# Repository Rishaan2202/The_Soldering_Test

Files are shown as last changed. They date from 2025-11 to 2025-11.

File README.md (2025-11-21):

# The_Soldering_Test
<h3> So this is a basic pcb, which has many kinda footprints in which we need to solder components, it has many basic and common footprints of SMT and THT devices, so that we could increase our soldering skills!!! </h3>
<br>
<br>

<h2> So here's the Schematic: </h2>
<br>

<br>
<br>

<h2> The PCB looks like this: </h2>
<br>

<br>
<h3> Front view </h3>
<br>

<h3> Back view </h3>
<br>

<br>
<br>

<h2> Here are the cart Pictures </h2>
<br>
<h3> The Parts' Cart: </h3>
<br>

<br>
<h3> The PCBs' Cart: </h3>

<br>
<br>

<h2> TYSM!!! </h2>

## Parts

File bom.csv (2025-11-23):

Designator | Footprint | Quantity | Value | LCSC Part # | Robocraze | Value (in USD)
C1, C2 | 402 | 2 | 10pF | C32949
C12, C13, C14, C16, C25 | 402 | 5 | 0.1uF | C1525
C15, C27, C28, C29 | 402 | 4 | 22uF | C105226
C17, C18, C19, C8 | 402 | 4 | 1uF | C52923
C23 | 402 | 1 | 4.7uF | C23733
C24, C26, C30, C31, C32, C6 | 402 | 6 | 10uF | C15525
D1, D2, D3 | 402 | 3 | LED | C30584803
IC1 | HSFPAR004A | 1 | HSFPAR004A | C470800
J1 | PinHeader_1x02_P2.54mm_Vertical_JST | 1 | Battery Connectors |  | 2.54mm pitch 2 pin JST Cable with Connector | 0.73
J2, J3 | PinHeader_1x04_P2.54mm_Vertical_Female | 1 | Conn_01x04 |  | 40x1 Female Berg Strip | 0.1
J6 | KH-TYPE-C-16P | 1 | USB Type-C Input | C709357
L1 | 805 | 1 | 1.5uH | C216155
Q1 | SOT-23 | 1 | SS8550 | C727138
R1 | 402 | 1 | 220Ω | C25091
R10, R12 | 402 | 2 | 1kΩ | C11702
R11 | 402 | 1 | 2kΩ | C4109
R14, R21 | 402 | 2 | 100kΩ | C25741
R15 | 402 | 1 | 470kΩ | C427225
R16 | 402 | 1 | 150kΩ | C2909320
R17, R24, R25, R30, R31, R32, R33, R34, R35, R36, R37 | 402 | 11 | 10kΩ | C25744
R2, R3 | 402 | 2 | 5kΩ | C5948099
R20 | 402 | 1 | 100Ω | C25076
R26, R27 | 402 | 2 | 22Ω | C25092
R28, R29 | 402 | 2 | 5.1kΩ | C25905
R5, R6, R8, R9 | 402 | 4 | 4.7kΩ | C25900
S1, S2 | SW_SKRPACE010 | 2 | SKRPACE010 | C139797
S3, S4 | Push Button | 2 | TS-1088-AR02016 | C720477
SW1 | SW_PCM12SMTR | 1 | PCM12SMTR | C221841
U1 | SOT-23-3L_AOS | 1 | AO3401A | C15127
U10 | VREG_TPS63070RNMR | 1 | TPS63070RNMR | C109322
U3 | WSON-8-1EP_2x2mm_P0.5mm_EP0.9x1.6mm_ThermalVias | 1 | TMP1075DSG | C2870250
U4 | ESP32-S3FN8 | 1 | ESP32-S3FN8 | C2913196
U5 | Crystal_SMD_3225-4Pin_3.2x2.5mm | 1 | SMD3225 | C5444549
U6 | SOP-16_3.9x9.9mm_P1.27mm | 1 | HX711 | C6705483
U9 | SOT23-6 | 1 | TP4057 | C725791
J7 | PinHeader_1x04_P2.54mm_Vertical_Male | 1 |  |  | 40x1 Pin 2.54mm Pitch Male Berg Strip | 0.056
Display1 | OLED Display | 1 |  |  | 0.96 Inch OLED Display Module SPI/I2C 4pin Blue Color | 3.52
GPS1 | GPS | 1 |  |  | Ublox Neo-6M GPS Module With EEPROM | 2.195
B1 | Li-ion Battery | 1 | Battery |  | Witty Fox 3.7V 2000 mAh Li-ion GPS Cylindrical Battery | 3.41
 |  |  |  |  |  | 10.011

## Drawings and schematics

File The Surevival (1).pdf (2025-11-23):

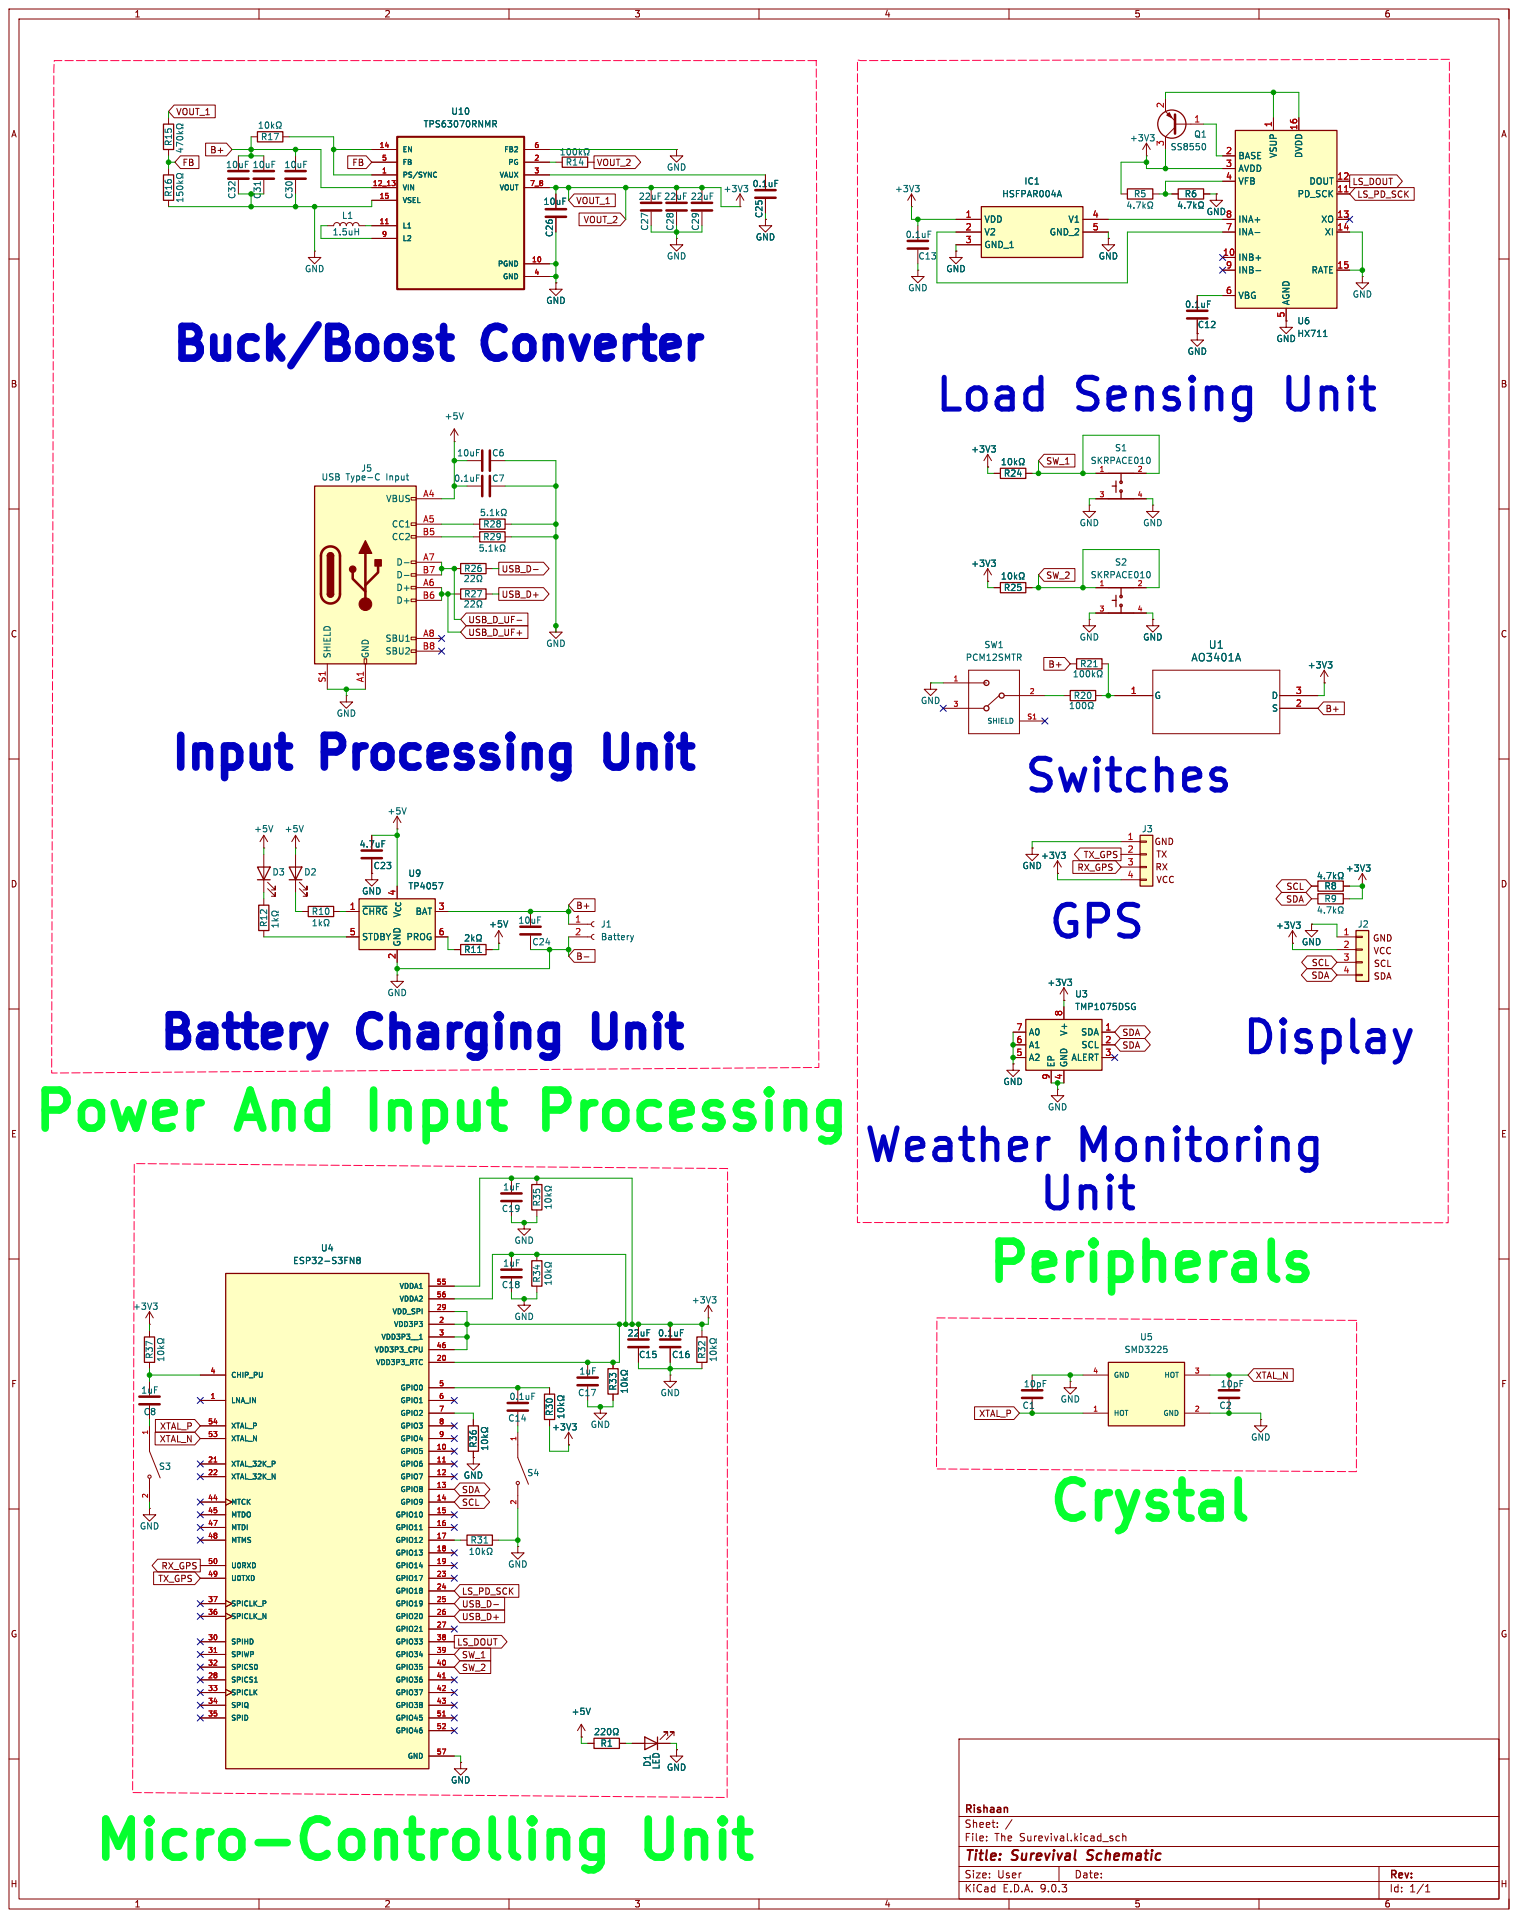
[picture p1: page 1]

5 DVDD 16 DOUT 12 PD_SCK 11 XO 13 XI 14 RATE 15 U6 HX711 C32

5 DVDD 16 DOUT 12 PD_SCK 11 XO 13 XI 14 RATE 15

2 BAT 3 PROG 6 U9 TP4057 +5V GND GND

Battery Charging Unit R36 þÿ10k© GND
Power And Input Processing

4 SDA 1 SCL 2 ALERT 3 +3V3 GND

Id: 1/1 Title: Surevival Schematic

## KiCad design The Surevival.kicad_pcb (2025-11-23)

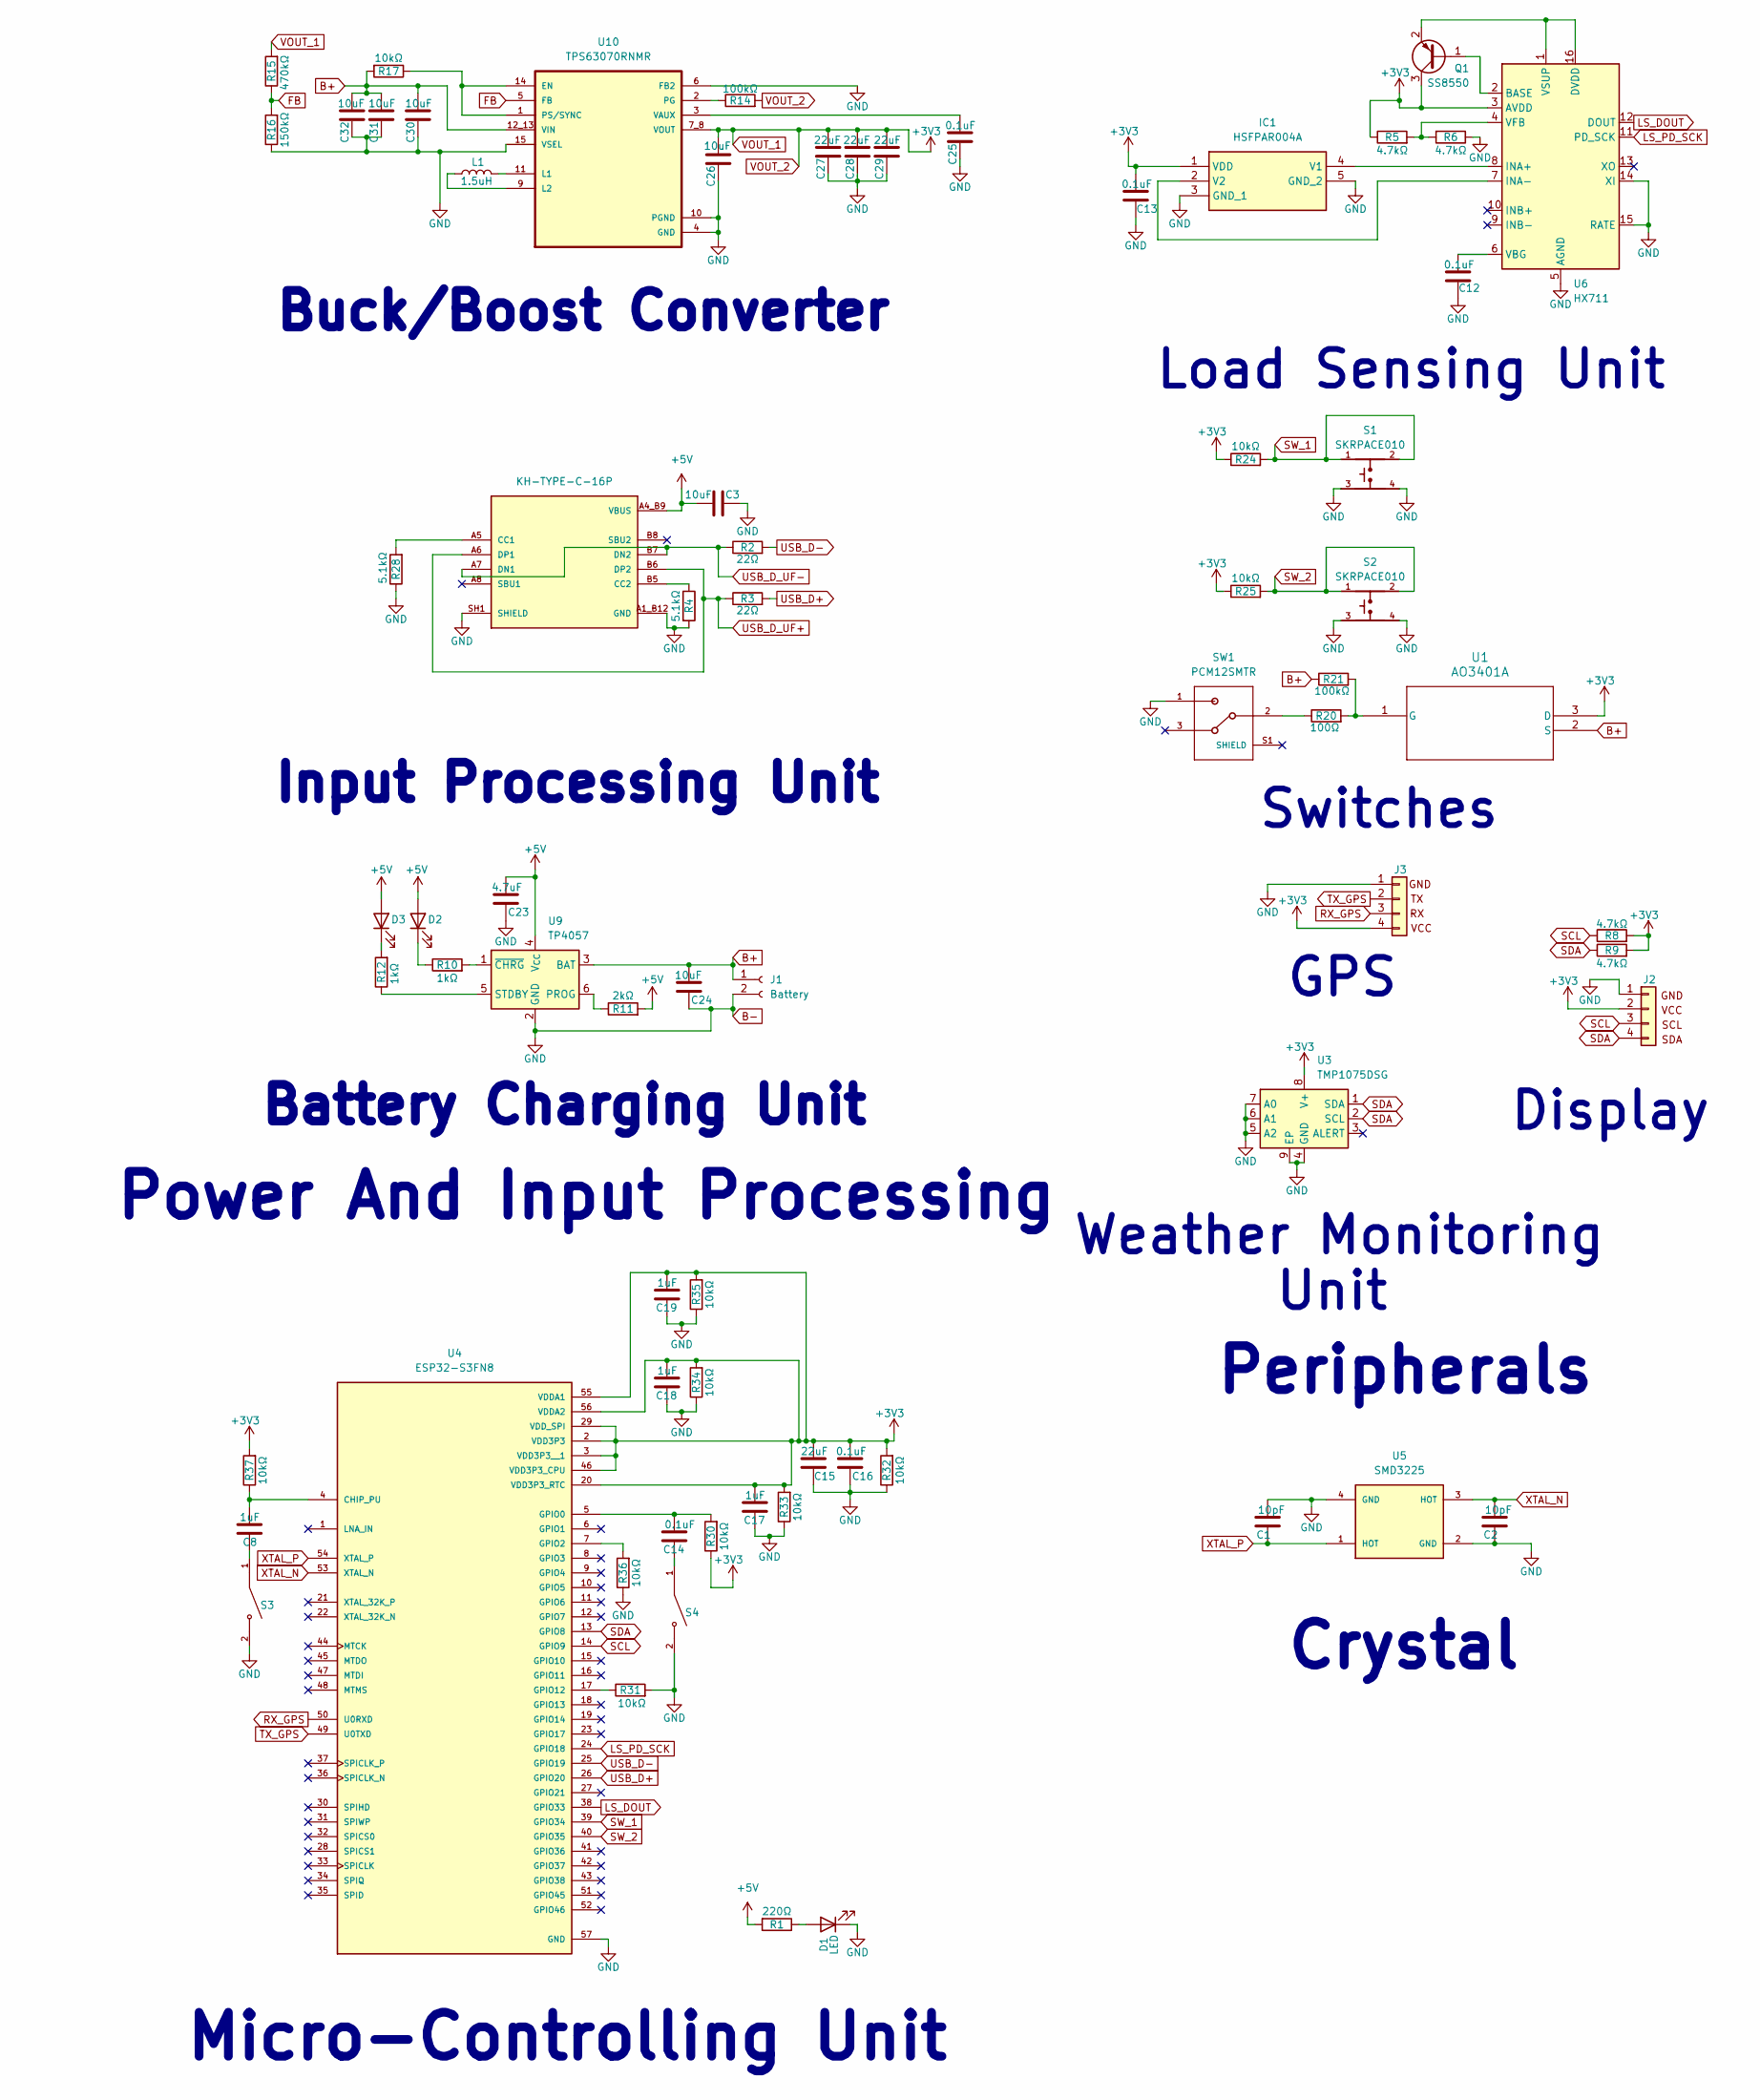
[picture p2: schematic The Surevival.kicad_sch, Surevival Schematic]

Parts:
C1, C2: 10pF; C_0402_1005Metric
C3, C24, C26, C30, C31, C32: 10uF; C_0402_1005Metric
C8, C17, C18, C19: 1uF; C_0402_1005Metric
C12, C13, C14, C16, C25: 0.1uF; C_0402_1005Metric
C15, C27, C28, C29: 22uF; C_0402_1005Metric
C23: 4.7uF; C_0402_1005Metric
D1, D2, D3: LED; LED_0402_1005Metric
IC1: HSFPAR004A; Mouser Part Number 688-HSFPAR004A
J1: Battery; PinHeader_1x02_P2.54mm_Vertical
J2, J3: Conn_01x04; PinHeader_1x04_P2.54mm_Vertical
J6: KH-TYPE-C-16P; KINGHELM_KH-TYPE-C-16P; PARTREV A0
L1: 1.5uH; L_0805_2012Metric
Q1: SS8550; SOT-23
R1: 220Ω; R_0402_1005Metric
R2, R3: 22Ω; R_0402_1005Metric
R4, R28: 5.1kΩ; R_0402_1005Metric
R5, R6, R8, R9: 4.7kΩ; R_0402_1005Metric
R10, R12: 1kΩ; R_0402_1005Metric
R11: 2kΩ; R_0402_1005Metric
R14, R21: 100kΩ; R_0402_1005Metric
R15: 470kΩ; R_0402_1005Metric
R16: 150kΩ; R_0402_1005Metric
R17, R24, R25, R30, R31, R32, R33, R34, R35, R36, R37: 10kΩ; R_0402_1005Metric
R20: 100Ω; R_0402_1005Metric
S1, S2: SKRPACE010; SW_SKRPACE010
S3, S4: TS-1088-AR02016; Push Button; PARTREV N/A
SW1: PCM12SMTR; SW_PCM12SMTR
U1: AO3401A; SOT-23-3L_AOS
U3: TMP1075DSG; WSON-8-1EP_2x2mm_P0.5mm_EP0.9x1.6mm_ThermalVias
U4: ESP32-S3FN8
U5: SMD3225; Crystal_SMD_3225-4Pin_3.2x2.5mm
U6: HX711; SOP-16_3.9x9.9mm_P1.27mm
U9: TP4057; SOT23-6
U10: TPS63070RNMR; VREG_TPS63070RNMR

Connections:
+5V: C3.1, C23.1, D2.2 (A), D3.2 (A), J6.A4_B9 (VBUS), J6.A9_B4 (VBUS), R1.2, R11.2, U9.4 (V_{CC})
B+: C24.1, C30.2, C31.2, C32.2, J1.1, R17.2, R21.1, U1.2 (S), U9.3 (BAT), U10.12_13 (VIN)
B-: C1.1, C2.2, C3.2, C12.2, C13.2, C15.2, C16.2, C17.2, C18.2, C19.2, C23.2, C24.2, C25.1, C26.1, C27.1, C28.1, C29.1, C30.1, C31.1, C32.1, D1.1 (K), IC1.3 (GND_1), IC1.5 (GND_2), J1.2, J2.1, J3.1, J6.A1_B12 (GND), J6.A12_B1 (GND), J6.SH1 (SHIELD), J6.SH2 (SHIELD), J6.SH3 (SHIELD), J6.SH4 (SHIELD), R4.2, R6.1, R16.1, R28.1, R31.2, R32.1, R33.1, R34.1, R35.1, R36.1, S1.3, S1.4, S2.3, S2.4, S3.2, S4.2, SW1.1, U3.4 (GND), U3.5 (A2), U3.6 (A1), U3.7 (A0), U3.9 (EP), U4.57 (GND), U5.2 (GND), U5.4 (GND), U6.5 (AGND), U6.14 (XI), U6.15 (RATE), U9.2 (GND), U10.4 (GND), U10.6 (FB2), U10.10 (PGND), U10.15 (VSEL)
FB: R15.1, R16.2, U10.5 (FB)
LS_DOUT: U4.38 (GPIO33), U6.12 (DOUT)
LS_PD_SCK: U4.24 (GPIO18), U6.11 (PD_SCK)
unnamed: C8.2, S3.1
unnamed: C14.2, S4.1
unnamed: D1.2 (A), R1.1
unnamed: D2.1 (K), R10.1
unnamed: D3.1 (K), R12.2
unnamed: IC1.4 (V1), U6.8 (INA+)
unnamed: IC1.2 (V2), U6.7 (INA-)
unnamed: J6.A5 (CC1), R28.2
unnamed: J6.B5 (CC2), R4.1
unnamed: Q1.1 (B), U6.2 (BASE)
unnamed: Q1.2 (E), U6.1 (VSUP), U6.16 (DVDD)
unnamed: R20.1, SW1.2
unnamed: R20.2, R21.2, U1.1 (G)
unnamed: C8.1, R37.1, U4.4 (CHIP_PU)
unnamed: C14.1, R30.2, U4.5 (GPIO0)
unnamed: R36.2, U4.7 (GPIO2)
unnamed: R31.1, U4.17 (GPIO12)
unnamed: C12.1, U6.6 (VBG)
unnamed: R5.2, R6.2, U6.4 (VFB)
unnamed: R11.1, U9.6 (PROG)
unnamed: R12.1, U9.5 (STDBY)
unnamed: R10.2, U9.1 (~CHRG)
unnamed: R17.1, U10.1 (PS/SYNC), U10.14 (EN)
unnamed: L1.2, U10.11 (L1)
unnamed: L1.1, U10.9 (L2)
unnamed: R14.1, U10.2 (PG)
unnamed: C25.2, U10.3 (VAUX)
RX_GPS: J3.3, U4.50 (U0RXD)
SCL: J2.3, R8.1, U4.14 (GPIO9)
SDA: J2.4, R9.1, U3.1 (SDA), U3.2 (SCL), U4.13 (GPIO8)
SW_1: R24.2, S1.1, S1.2, U4.39 (GPIO34)
SW_2: R25.2, S2.1, S2.2, U4.40 (GPIO35)
TX_GPS: J3.2, U4.49 (U0TXD)
USB_D+: R3.2, U4.26 (GPIO20)
USB_D-: R2.2, U4.25 (GPIO19)
USB_D_UF+: J6.A6 (DP1), J6.B6 (DP2), R3.1
USB_D_UF-: J6.A7 (DN1), J6.B7 (DN2), R2.1
VOUT_1: C13.1, C15.1, C16.1, C17.1, C18.1, C19.1, C26.2, C27.2, C28.2, C29.2, IC1.1 (VDD), J2.2, J3.4, Q1.3 (C), R5.1, R8.2, R9.2, R14.2, R15.2, R24.1, R25.1, R30.1, R32.2, R33.2, R34.2, R35.2, R37.2, U1.3 (D), U3.8 (V+), U4.2 (VDD3P3), U4.3 (VDD3P3__1), U4.20 (VDD3P3_RTC), U4.29 (VDD_SPI), U4.46 (VDD3P3_CPU), U4.55 (VDDA1), U4.56 (VDDA2), U6.3 (AVDD), U10.7_8 (VOUT)
XTAL_N: C2.1, U4.53 (XTAL_N), U5.3 (HOT)
XTAL_P: C1.2, U4.54 (XTAL_P), U5.1 (HOT)

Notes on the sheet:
Unit
Switches
Battery Charging Unit
Peripherals
Buck/Boost Converter
GPS
Power And Input Processing
Micro-Controlling Unit
Input Processing Unit
Weather Monitoring
Load Sensing Unit
Display
Crystal

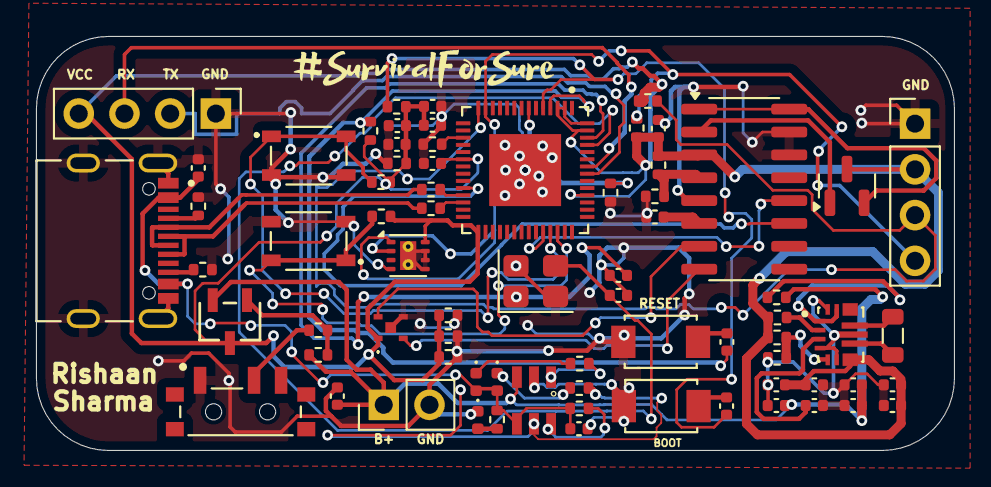
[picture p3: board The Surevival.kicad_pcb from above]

Board: 2 copper layers, 51.0 x 23.0 mm, 72 parts (0 on the bottom side), 46 nets.
